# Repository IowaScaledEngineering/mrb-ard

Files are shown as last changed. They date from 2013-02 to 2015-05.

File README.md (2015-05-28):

MRB-ARD: MRBus Interface Shield for Arduino
--------------------------------

This project contains the design files for the MRB-ARD, an Arduino-compatible shield 
that allows Arduinos to be connected to RS485 networks such as MRBus.  It also includes
the standard Iowa Scaled Engineering I2C 6p6c jack, the jumper-selectable ability to 
power the Arduino from MRBus power, and jumper-selectable RS485 bias resistors for holding
the bus in a 1 state while it's not being actively driven.

Known Issues:
* Because the RS485 interface uses the same serial port as the console/bootloader on Arduinos like the Uno, you cannot have the shield installed and talk to the PC at the same time.  This, however, works just fine on the Leonardo, as its console port is virtual via USB.
* The Leonardo has one of its I2C pins (SDA) shared with digital I/O 2, which is what the shield uses for RS485 TX/RX direction.  Thus, you can't use I2C with the Leonardo.
* The board is 5V only.  It will not work with Arduinos like the Due, which require 3.3V I/O.

MRBus for Arduino Library
--------------------------------

The project also contains the MRBusArduino library, which can be used to connect AVR-based Arduinos to MRBus.  The library is
under the src/ directory.  To install it, copy the MRBusArduino directory to your Arduino libraries/ directory.

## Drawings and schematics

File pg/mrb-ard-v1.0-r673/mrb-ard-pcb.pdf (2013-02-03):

# mrb-ard.pcb

# 1. Table of Contents (This Page) Created on Sat Feb 2 16:25:27 2013

# 2. component 3. solder 4. outline 5. plated-drill 6. componentmask 7. soldermask 8. topsilk 9. bottomsilk 10. toppaste 11. topassembly 12. bottomassembly 13. fab

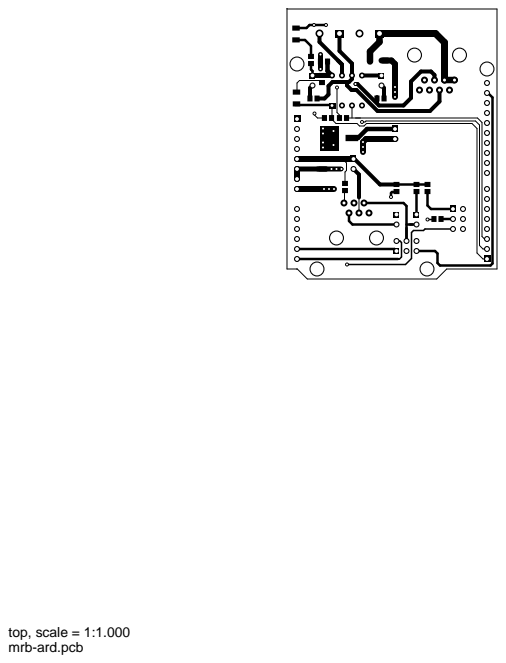
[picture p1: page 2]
top, scale = 1:1.000

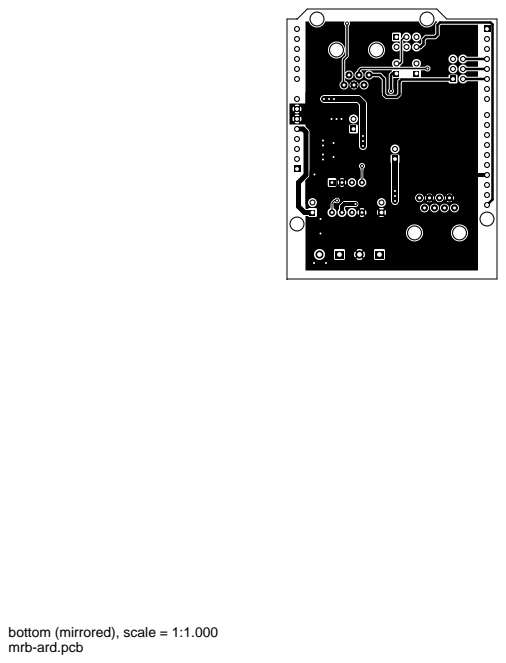
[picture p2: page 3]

bottom (mirrored), scale = 1:1.000

outline, scale = 1:1.000

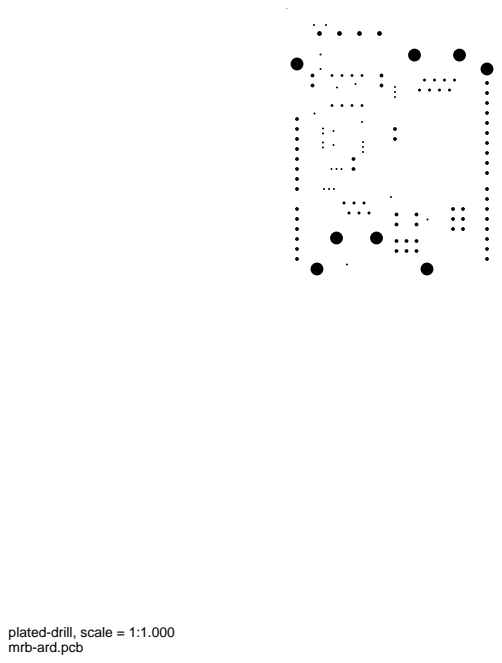
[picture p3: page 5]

plated-drill, scale = 1:1.000

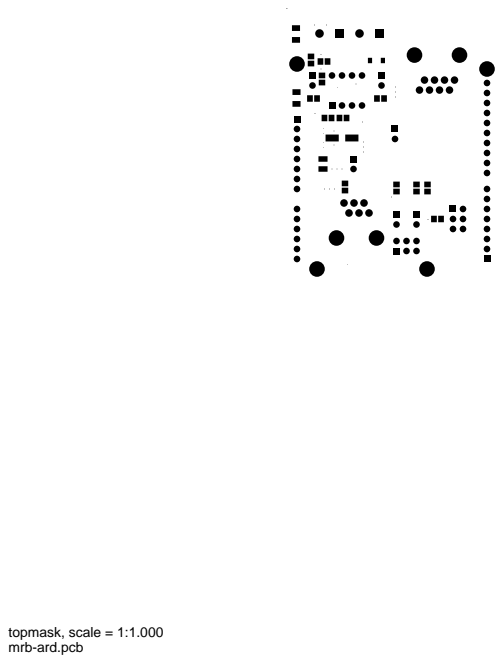
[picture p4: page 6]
topmask, scale = 1:1.000

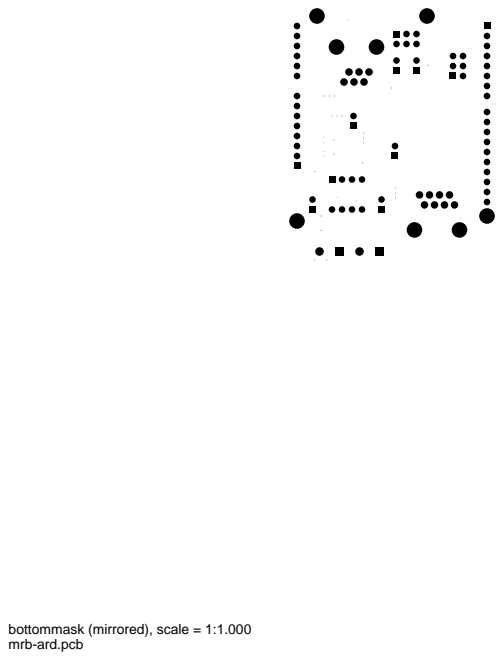
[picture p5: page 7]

bottommask (mirrored), scale = 1:1.000

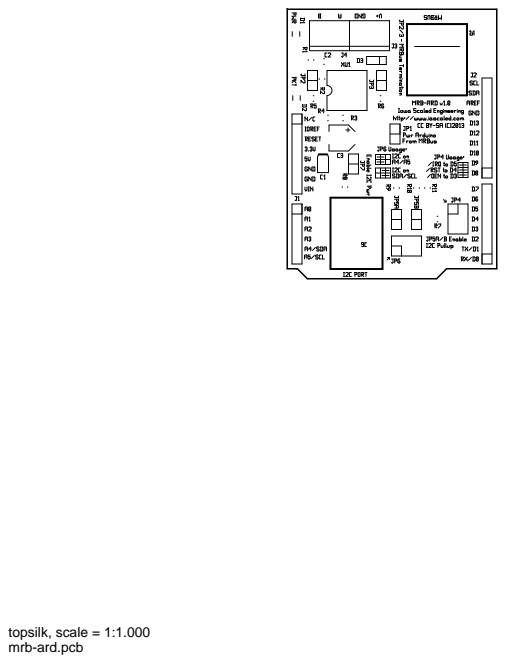
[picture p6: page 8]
topsilk, scale = 1:1.000

bottomsilk (mirrored), scale = 1:1.000

toppaste, scale = 1:1.000

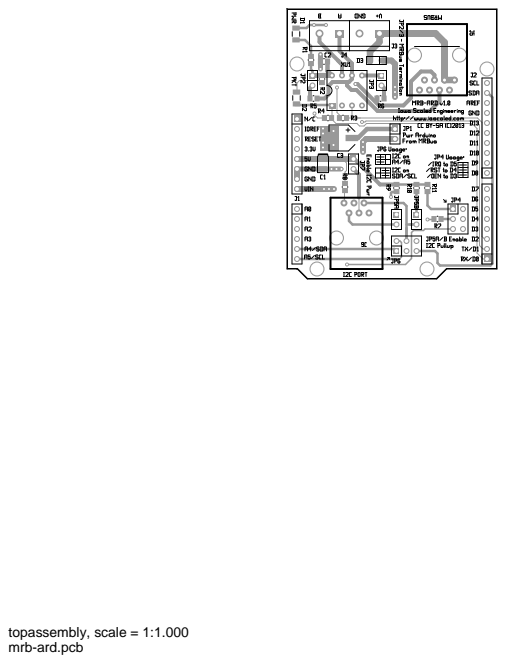
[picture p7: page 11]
topassembly, scale = 1:1.000

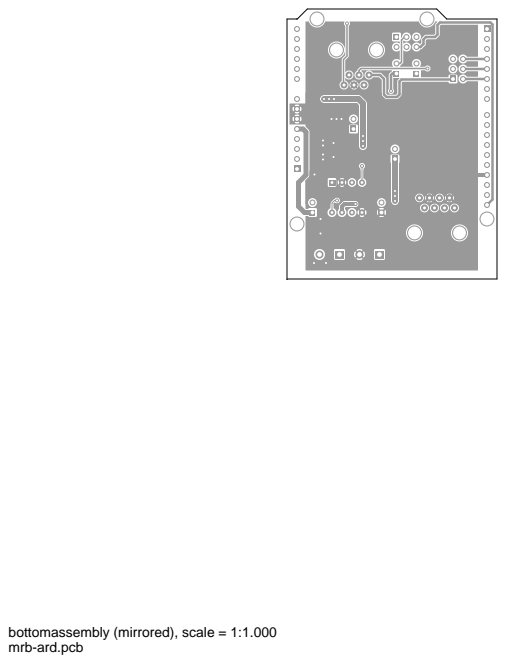
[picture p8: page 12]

bottomassembly (mirrored), scale = 1:1.000

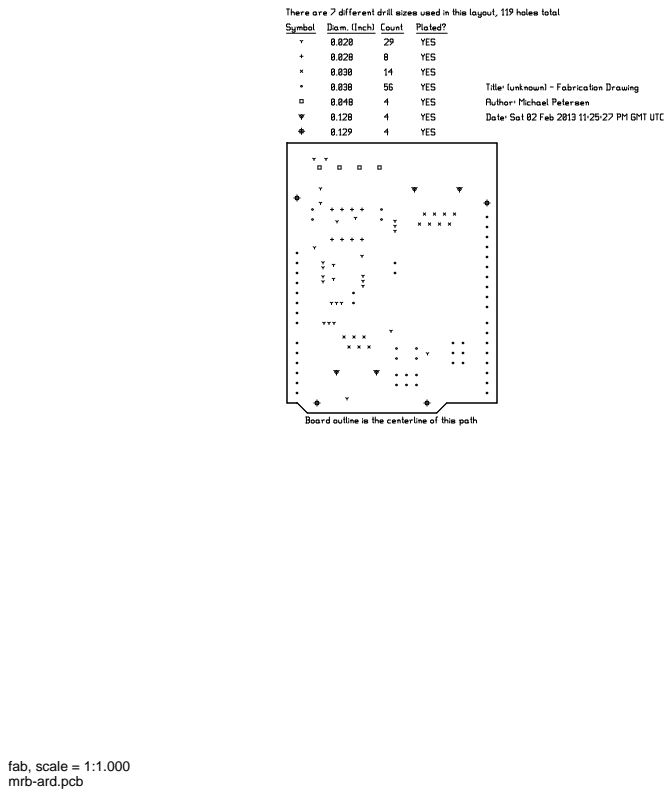
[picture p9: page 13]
fab, scale = 1:1.000

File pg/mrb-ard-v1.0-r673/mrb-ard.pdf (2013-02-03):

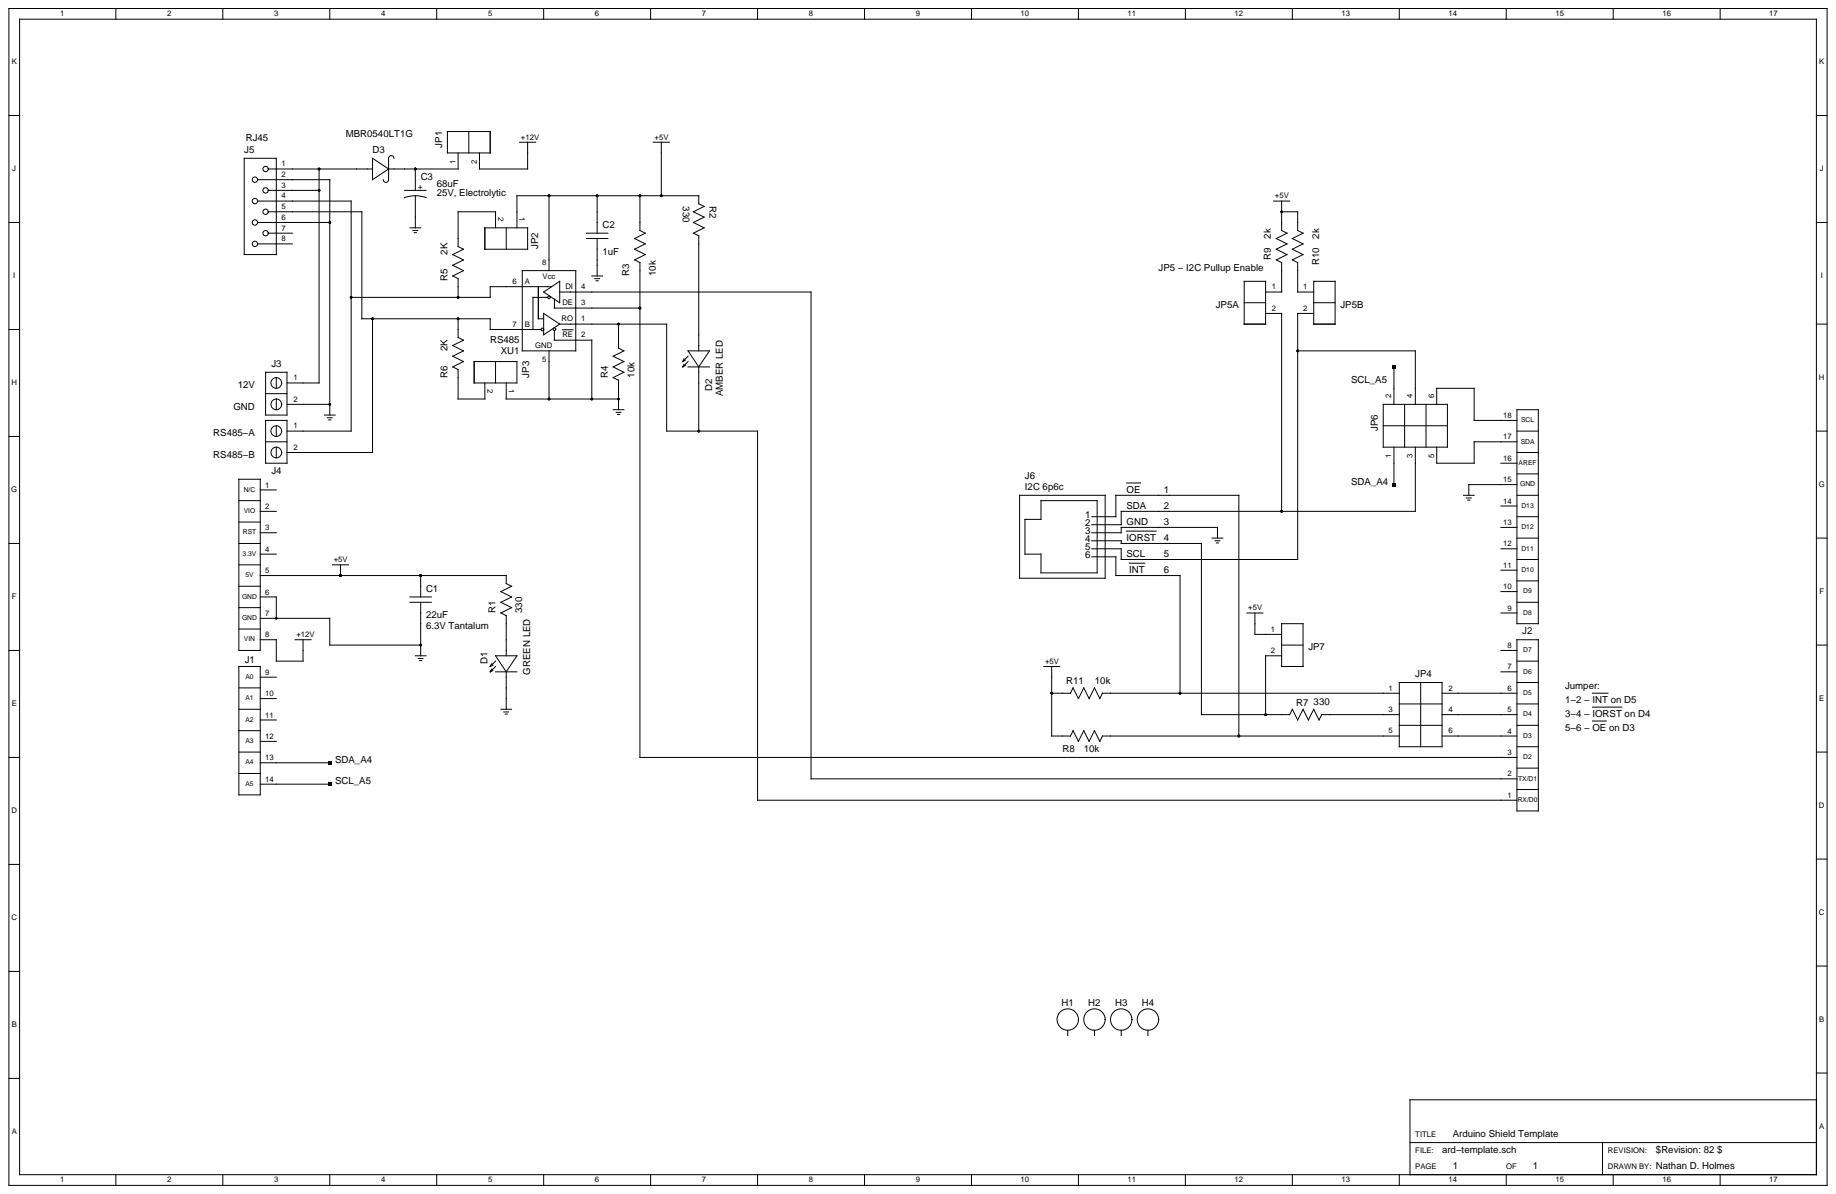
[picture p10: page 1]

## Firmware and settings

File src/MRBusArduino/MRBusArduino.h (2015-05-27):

/*************************************************************************
Title:    MRBus Arduino Library Header
Authors:  Nathan Holmes <maverick@drgw.net>, Colorado, USA
          Michael Petersen <railfan@drgw.net>, Colorado, USA
          Michael Prader, South Tyrol, Italy
File:     MRBusArduino.h
License:  GNU General Public License v3

LICENSE:
    Copyright (C) 2015 Nathan Holmes, Michael Petersen, and Michael Prader
    
    The MRBus library provides a way to easily interface Arduino applications
    with MRBus-based networks.  While written to be used with the Iowa Scaled
    Engineering mrb-ard shield, it should be easily compatible with any RS485
    driver hooked up to an Arduino serial port appropriately.
    
    The latest source can be obtained from ISE's Github repository here:
    https://github.com/IowaScaledEngineering/mrb-ard

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
*************************************************************************/

#ifndef MRBUS_AVR_H
#define MRBUS_AVR_H

#include <stdlib.h>
#include <avr/io.h>

// Size definitions
#define MRBUS_BUFFER_SIZE  0x14

// Packet component defines
#define MRBUS_PKT_DEST  0
#define MRBUS_PKT_SRC   1
#define MRBUS_PKT_LEN   2
#define MRBUS_PKT_CRC_L 3
#define MRBUS_PKT_CRC_H 4
#define MRBUS_PKT_TYPE  5
#define MRBUS_PKT_SUBTYPE 6

// mrbus_status masks
#define MRBUS_RX_PKT_READY    0x01
#define MRBUS_RX_PKT_OVERFLOW 0x02
#define MRBUS_TX_BUF_ACTIVE   0x40
#define MRBUS_TX_PKT_READY    0x80

// mrbus_activity states
#define MRBUS_ACTIVITY_IDLE          0
#define MRBUS_ACTIVITY_RX            1
#define MRBUS_ACTIVITY_RX_COMPLETE   2

// Specification-defined EEPROM Addresses
#define MRBUS_EE_DEVICE_ADDR         0
#define MRBUS_EE_DEVICE_OPT_FLAGS    1
#define MRBUS_EE_DEVICE_UPDATE_H     2
#define MRBUS_EE_DEVICE_UPDATE_L     3

// Version flags
#define MRBUS_VERSION_WIRELESS 0x80
#define MRBUS_VERSION_WIRED    0x00

#define MRBUS_BAUD   57600

// AVR type-specific stuff
// Define the UART port and registers used for XBee communication
// Follows the format of the AVR UART library by Fleury/Sharpe

#if defined(__AVR_ATmega162__)

#define MRBUS_ATMEGA_USART0_SIMPLE
#define MRBUS_UART_RX_INTERRUPT    USART0_RXC_vect
#define MRBUS_UART_TX_INTERRUPT    USART0_UDRE_vect
#define MRBUS_UART_DONE_INTERRUPT  USART0_TXC_vect
#define MRBUS_PORT                 PORTD
#define MRBUS_PIN                  PIND
#define MRBUS_DDR                  DDRD

#ifndef MRBUS_TXE
#define MRBUS_TXE                  2       /* PD2 */
#endif
#ifndef MRBUS_TX
#define MRBUS_TX                   1       /* PD1 */
#endif
#ifndef MRBUS_RX
#define MRBUS_RX                   0       /* PD0 */
#endif

#define MRBUS_UART_UBRR            UBRR0L
#define MRBUS_UART_SCR_A           UCSR0A
#define MRBUS_UART_SCR_B           UCSR0B
#define MRBUS_UART_SCR_C           UCSR0C
#define MRBUS_UART_DATA            UDR0
#define MRBUS_UART_UDRIE           UDRIE0
#define MRBUS_RXEN                 RXEN0
#define MRBUS_TXEN                 TXEN0
#define MRBUS_RXCIE                RXCIE0
#define MRBUS_TXCIE                TXCIE0
#define MRBUS_RX_ERR_MASK          (_BV(FE0) | _BV(DOR0))



#elif  defined(__AVR_ATmega8__)

#define MRBUS_ATMEGA_USART_SIMPLE
#define MRBUS_UART_RX_INTERRUPT    USART_RXC_vect
#define MRBUS_UART_TX_INTERRUPT    USART_UDRE_vect
#define MRBUS_UART_DONE_INTERRUPT  USART_TXC_vect
#define MRBUS_PORT                 PORTD
#define MRBUS_PIN                  PIND
#define MRBUS_DDR                  DDRD

#ifndef MRBUS_TXE
#define MRBUS_TXE                  2       /* PD2 */
#endif
#ifndef MRBUS_TX
#define MRBUS_TX                   1       /* PD1 */
#endif
#ifndef MRBUS_RX
#define MRBUS_RX                   0       /* PD0 */
#endif

#define MRBUS_UART_UBRR            UBRRL
#define MRBUS_UART_SCR_A           UCSRA
#define MRBUS_UART_SCR_B           UCSRB
#define MRBUS_UART_SCR_C           UCSRC
#define MRBUS_UART_DATA            UDR
#define MRBUS_UART_UDRIE           UDRIE
#define MRBUS_RXEN                 RXEN
#define MRBUS_TXEN                 TXEN
#define MRBUS_RXCIE                RXCIE
#define MRBUS_TXCIE                TXCIE
#define MRBUS_RX_ERR_MASK          (_BV(FE) | _BV(DOR))



#elif defined(__AVR_ATmega48__) ||defined(__AVR_ATmega88__) || defined(__AVR_ATmega168__) || \
    defined(__AVR_ATmega48P__) ||defined(__AVR_ATmega88P__) || defined(__AVR_ATmega168P__) || \
    defined(__AVR_ATmega328P__) 
#define MRBUS_ATMEGA_USART
#define MRBUS_UART_RX_INTERRUPT    USART_RX_vect
#define MRBUS_UART_TX_INTERRUPT    USART_UDRE_vect
#define MRBUS_UART_DONE_INTERRUPT  USART_TX_vect
#define MRBUS_PORT                 PORTD
#define MRBUS_PIN                  PIND
#define MRBUS_DDR                  DDRD

#ifndef MRBUS_TXE
#define MRBUS_TXE                  2       /* PD2 */
#endif
#ifndef MRBUS_TX
#define MRBUS_TX                   1       /* PD1 */
#endif
#ifndef MRBUS_RX
#define MRBUS_RX                   0       /* PD0 */
#endif

#define MRBUS_UART_UBRR            UBRR0
#define MRBUS_UART_SCR_A           UCSR0A
#define MRBUS_UART_SCR_B           UCSR0B
#define MRBUS_UART_SCR_C           UCSR0C
#define MRBUS_UART_DATA            UDR0
#define MRBUS_UART_UDRIE           UDRIE0
#define MRBUS_RXEN                 RXEN0
#define MRBUS_TXEN                 TXEN0
#define MRBUS_RXCIE                RXCIE0
#define MRBUS_TXCIE                TXCIE0
#define MRBUS_RX_ERR_MASK          (_BV(FE0) | _BV(DOR0))

#elif defined(__AVR_ATmega32U4__)

#define MRBUS_ATMEGA_USART1
#define MRBUS_UART_RX_INTERRUPT    USART1_RX_vect
#define MRBUS_UART_TX_INTERRUPT    USART1_UDRE_vect
#define MRBUS_UART_DONE_INTERRUPT  USART1_TX_vect
#define MRBUS_PORT                 PORTD
#define MRBUS_PIN                  PIND
#define MRBUS_DDR                  DDRD

#ifndef MRBUS_TXE
#define MRBUS_TXE                  1       /* PD2 */
#endif
#ifndef MRBUS_TX
#define MRBUS_TX                   3       /* PD1 */
#endif
#ifndef MRBUS_RX
#define MRBUS_RX                   2       /* PD0 */
#endif


#define MRBUS_UART_UBRR           UBRR1
#define MRBUS_UART_SCR_A          UCSR1A
#define MRBUS_UART_SCR_B          UCSR1B
#define MRBUS_UART_SCR_C          UCSR1C
#define MRBUS_UART_DATA           UDR1
#define MRBUS_UART_UDRIE          UDRIE1
#define MRBUS_RXEN                RXEN1
#define MRBUS_TXEN                TXEN1
#define MRBUS_RXCIE               RXCIE1
#define MRBUS_TXCIE               TXCIE1
#define MRBUS_RX_ERR_MASK         (_BV(FE1) | _BV(DOR1))


#elif defined(__AVR_ATmega164P__) || defined(__AVR_ATmega324P__) || \
    defined(__AVR_ATmega644P__) || defined(__AVR_ATmega1284P__)

#define MRBUS_ATMEGA_USART0
#define MRBUS_UART_RX_INTERRUPT    USART0_RX_vect
#define MRBUS_UART_TX_INTERRUPT    USART0_UDRE_vect
#define MRBUS_UART_DONE_INTERRUPT  USART0_TX_vect
#define MRBUS_PORT                 PORTD
#define MRBUS_PIN                  PIND
#define MRBUS_DDR                  DDRD
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

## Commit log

2012-12-31 Added mrbw-ard
    [mrbw-ard.sch]
2013-01-18 Latest updates to the mrbus aardvark, for transfer to my desktop machine
    [mrbw-ard.sch]
2013-01-22 More cleanup
    [mrb-ard.sch, mrbw-ard.sch]
2013-01-23 Changes to PCB per Petersen
2013-01-23 All sorts of cleanup to the ard board Added input cap on the mrbus power rail
    [mrb-ard.sch]
2013-01-23 Replaced the old 6p6c connector with the one that has annotated pins for I2C
    [mrb-ard.sch]
2013-01-25 MRBus Arduino shield library
2013-01-26 Changes to fix the arduino library
2013-02-02 Yay ground!
2013-02-03 Added PG files.
    [mrb-ard.bottom.gbr, mrb-ard.bottommask.gbr, mrb-ard.fab.gbr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]
